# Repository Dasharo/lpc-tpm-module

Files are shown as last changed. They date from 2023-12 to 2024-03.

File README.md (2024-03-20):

# LPC TPM module

TPM module PCB project for platforms with 2x5 pin, 2.54mm pitch LPC header
and 2x10 pin, 2.54mm pitch LPC header compatible with PC Engines platforms.

## Description

Trusted Platform Module compatible with:

1. 2x5pin LPC header populated on:
  * PC Engines apu3 platforms (from apu3d revision and onwards)
  * PC Engines apu4 platforms (from apu4c revision and onwards)
  * PC Engines apu6 platforms (all revisions)
2. 2x10pin LPC header populated on:
  * PC Engines apu2 platforms (all revisions)
  * PC Engines apu1 platforms (all revisions).

Design based on original [PC Engines TPM1A](https://pcengines.ch/schema/tpm1a.pdf).

TPM module can be used for:

* disk encryption
* password protection
* platform integrity and other security issues

TPM module features:

* TPM Infineon SLB9665TT2.0
* Operating voltage 3-3.3V
* Meeting Intel TXT, Microsoft Windows and Google Chromebook certification
  criteria for successful platform qualification
* True Random Number Generator (TRNG)
* Full personalization with Endorsement Key (EK) and EK certificate
* Supports the LPC interface

## Pinout

The pin layout is compatible with PC Engines platforms:

1. 2x5pin LPC header:

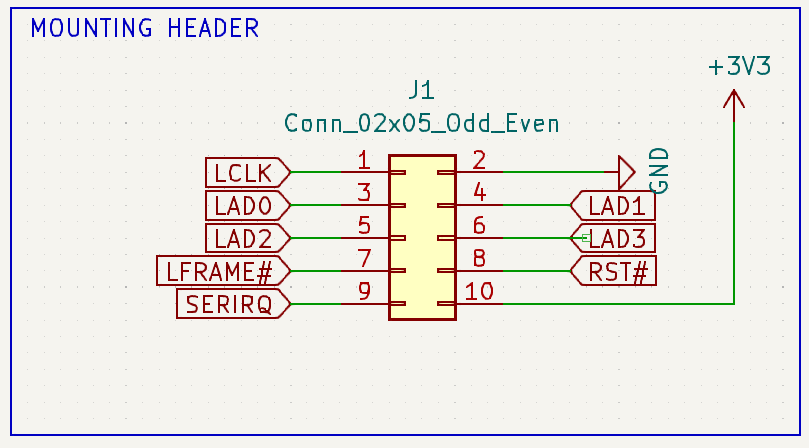
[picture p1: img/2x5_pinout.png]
2x5pin LPC header
  

2. 2x10pin LPC header:

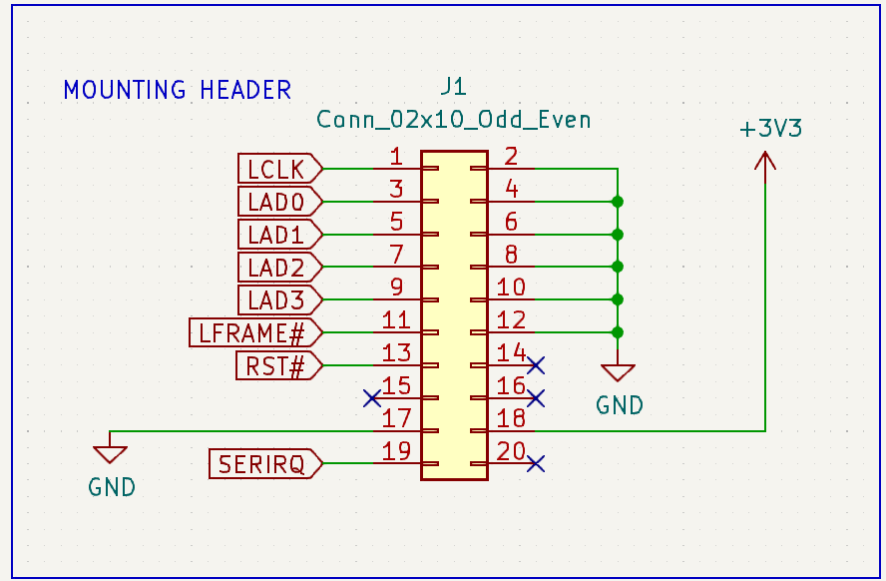
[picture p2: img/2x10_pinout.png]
2x10pin LPC header
  

## License

* Hardware is licensed under [CERN license](LICENSE.txt)
* Documentation is licensed under [CC BY-SA license](https://creativecommons.org/licenses/by-sa/2.0/)

## Where can I buy this product?

If you are not the enthusiast of DYI, then the plug and play product can be
bought in the [3mdeb shop](https://shop.3mdeb.com/product-category/modules/).

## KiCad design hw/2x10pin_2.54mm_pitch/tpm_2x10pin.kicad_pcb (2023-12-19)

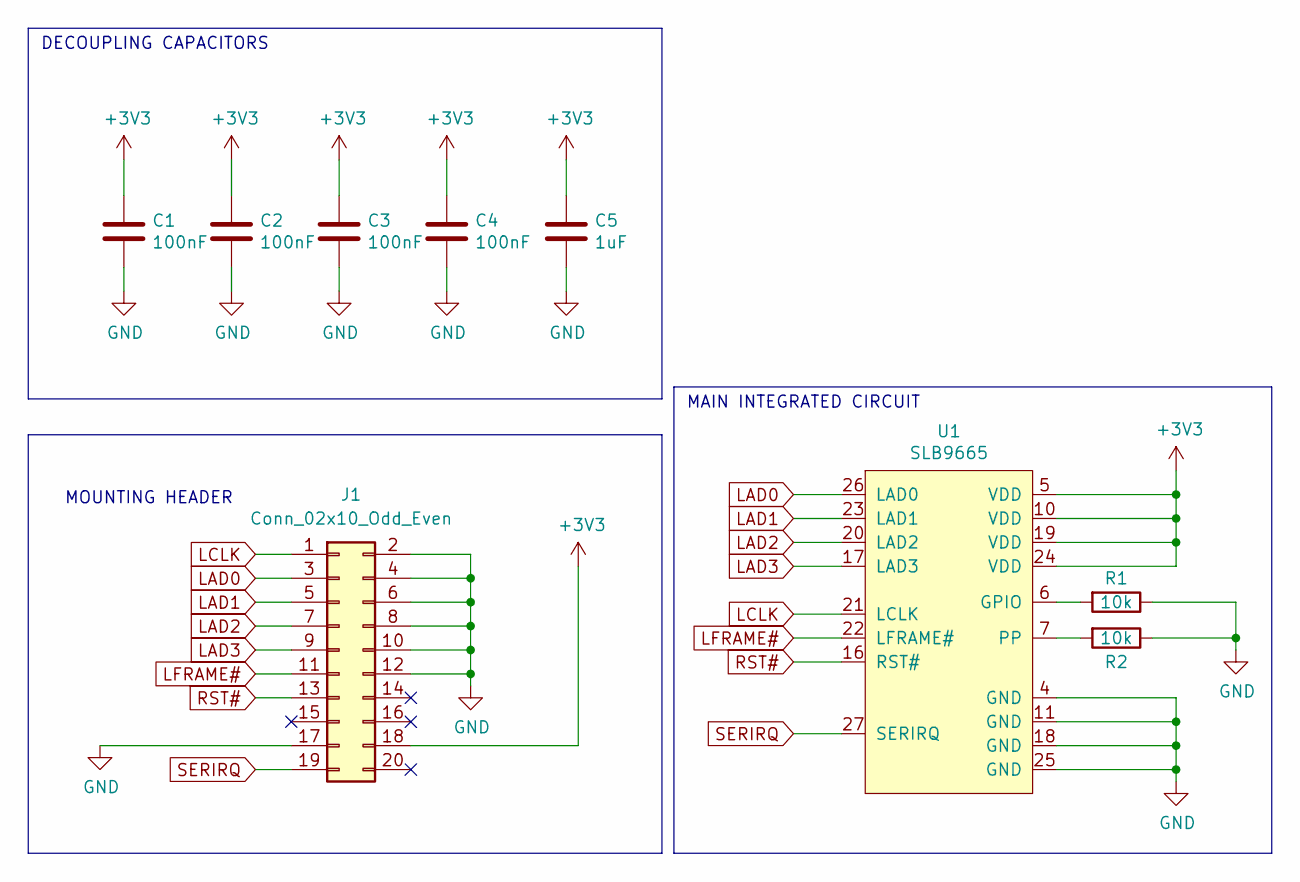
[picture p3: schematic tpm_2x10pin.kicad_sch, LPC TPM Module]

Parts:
C1, C2, C3, C4: 100nF; C_0603_1608Metric
C5: 1uF; C_0603_1608Metric
J1: Conn_02x10_Odd_Even; PinSocket_2x10_P2.54mm_Vertical
R1, R2: 10k; R_0603_1608Metric
U1: SLB9665; TSSOP-28_4.4x9.7mm_P0.65mm

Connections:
+3V3: C1.1, C2.1, C3.1, C4.1, C5.1, J1.18, U1.5 (VDD), U1.10 (VDD), U1.19 (VDD), U1.24 (VDD)
GND: C1.2, C2.2, C3.2, C4.2, C5.2, J1.2, J1.4, J1.6, J1.8, J1.10, J1.12, J1.17, R1.1, R2.1, U1.4 (GND), U1.11 (GND), U1.18 (GND), U1.25 (GND)
LAD0: J1.3, U1.26 (LAD0)
LAD1: J1.5, U1.23 (LAD1)
LAD2: J1.7, U1.20 (LAD2)
LAD3: J1.9, U1.17 (LAD3)
LCLK: J1.1, U1.21 (LCLK)
LFRAME#: J1.11, U1.22 (LFRAME#)
unnamed: R1.2, U1.6 (GPIO)
unnamed: R2.2, U1.7 (PP)
RST#: J1.13, U1.16 (RST#)
SERIRQ: J1.19, U1.27 (SERIRQ)

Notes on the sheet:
DECOUPLING CAPACITORS
MAIN INTEGRATED CIRCUIT
MOUNTING HEADER

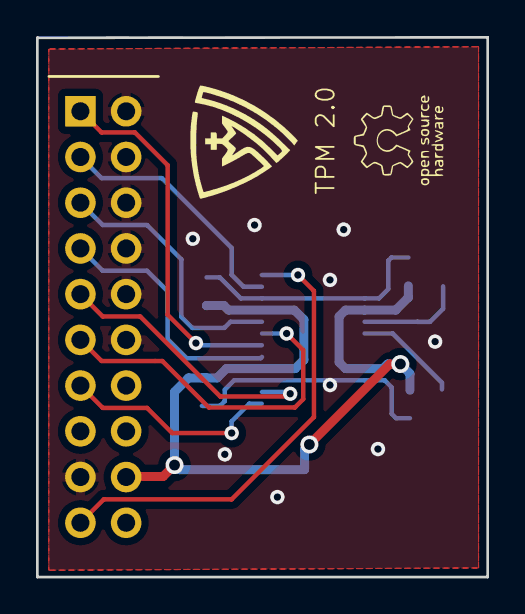
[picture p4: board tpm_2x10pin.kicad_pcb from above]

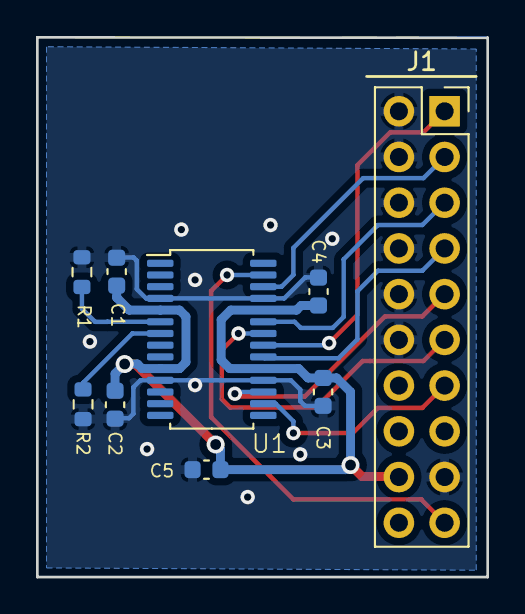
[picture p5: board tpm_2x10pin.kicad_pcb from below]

Board: 2 copper layers, 25.0 x 30.0 mm, 9 parts (9 on the bottom side), 12 nets.

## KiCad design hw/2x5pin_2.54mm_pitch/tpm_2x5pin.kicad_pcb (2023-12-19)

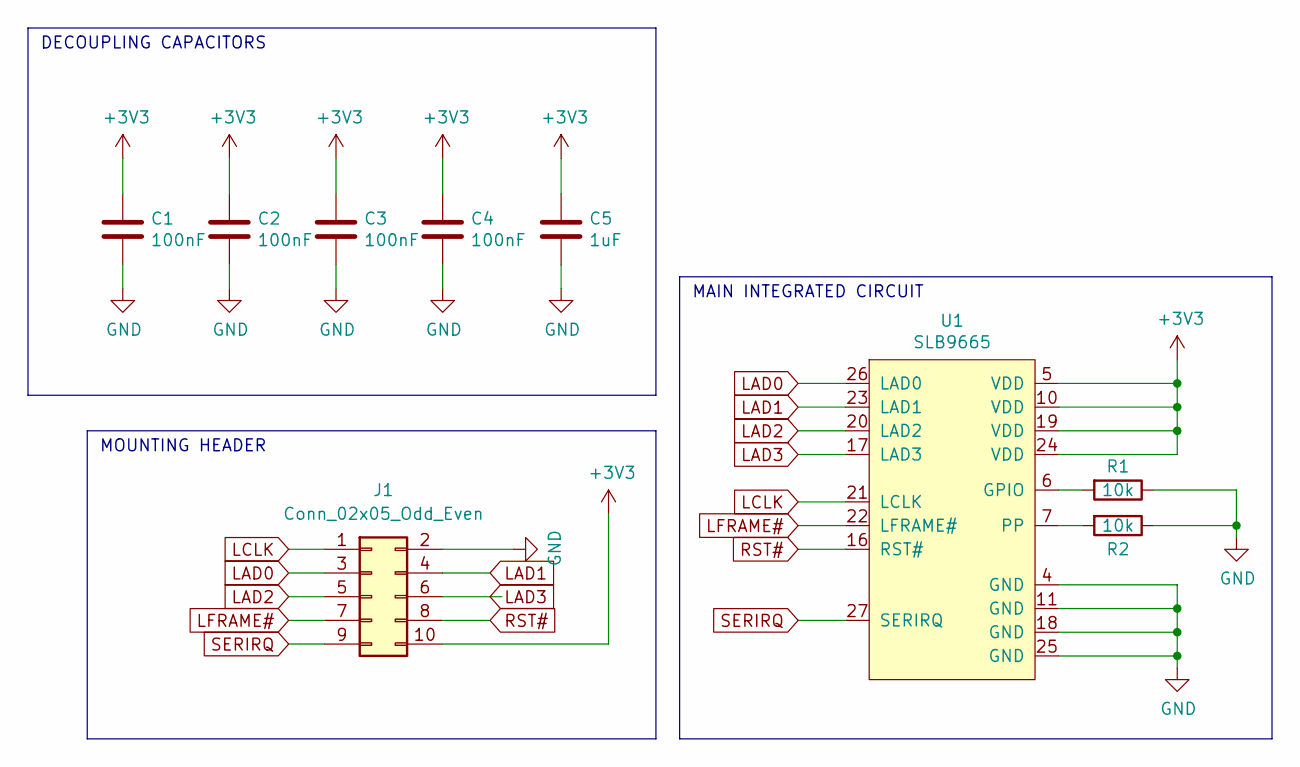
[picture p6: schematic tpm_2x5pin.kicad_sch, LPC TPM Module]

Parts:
C1, C2, C3, C4: 100nF; C_0603_1608Metric
C5: 1uF; C_0603_1608Metric
J1: Conn_02x05_Odd_Even; PinSocket_2x05_P2.54mm_Vertical
R1, R2: 10k; R_0603_1608Metric
U1: SLB9665; TSSOP-28_4.4x9.7mm_P0.65mm

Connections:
+3V3: C1.1, C2.1, C3.1, C4.1, C5.1, J1.10, U1.5 (VDD), U1.10 (VDD), U1.19 (VDD), U1.24 (VDD)
GND: C1.2, C2.2, C3.2, C4.2, C5.2, J1.2, R1.1, R2.1, U1.4 (GND), U1.11 (GND), U1.18 (GND), U1.25 (GND)
LAD0: J1.3, U1.26 (LAD0)
LAD1: J1.4, U1.23 (LAD1)
LAD2: J1.5, U1.20 (LAD2)
LAD3: J1.6, U1.17 (LAD3)
LCLK: J1.1, U1.21 (LCLK)
LFRAME#: J1.7, U1.22 (LFRAME#)
unnamed: R1.2, U1.6 (GPIO)
unnamed: R2.2, U1.7 (PP)
RST#: J1.8, U1.16 (RST#)
SERIRQ: J1.9, U1.27 (SERIRQ)

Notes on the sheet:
DECOUPLING CAPACITORS
MAIN INTEGRATED CIRCUIT
MOUNTING HEADER

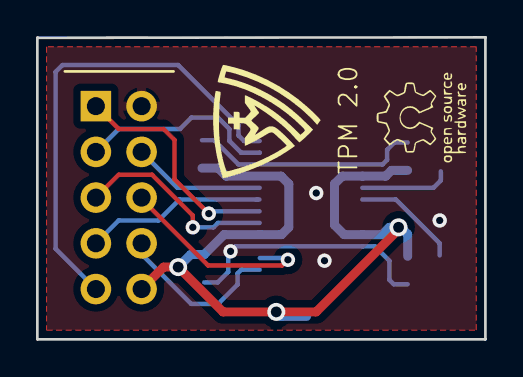
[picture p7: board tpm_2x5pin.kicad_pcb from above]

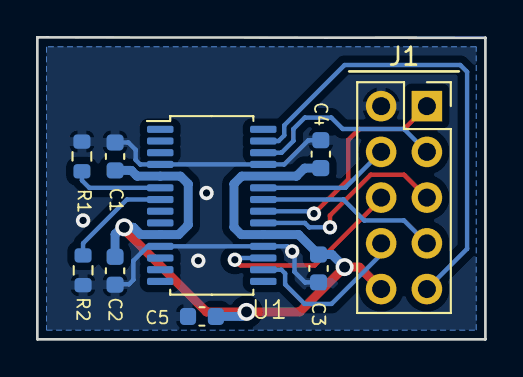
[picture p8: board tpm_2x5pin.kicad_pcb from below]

Board: 2 copper layers, 24.9 x 16.8 mm, 9 parts (9 on the bottom side), 12 nets.

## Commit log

2023-12-13 Add 2x5pin LPC header 2.54mm pitch TPM project
    [tpm_2x5pin.kicad_pcb, tpm_2x5pin.kicad_sch]
2023-12-13 Add 2x10pin LPC header 2.54mm pitch TPM project
    [tpm_2x10pin.kicad_pcb, tpm_2x10pin.kicad_sch]
2023-12-13 hw/2x10pin_2.54mm_pitch: Update proejct files with proper BOM
    [tpm_2x10pin.kicad_pcb, tpm_2x10pin.kicad_sch]
2023-12-19 Add UserComments layer with board setup and characteristics
    [tpm_2x10pin.kicad_pcb, tpm_2x10pin.kicad_sch, tpm_2x5pin.kicad_pcb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]
